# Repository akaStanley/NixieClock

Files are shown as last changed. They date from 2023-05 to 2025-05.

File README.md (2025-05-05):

# Nixie Tube Clock
From scratch design of a Nixie Tube Clock, with a twist. This clock sets its time using a GPS reciever, so it has the correct time anywhere around the world--and you don't have set it.

Read the "Notes on Nixie Tube Clock.rtf" for more details on the actual design. Here are some images of the design.
All the Code, PCB, and 3D model files are included here if you want to make your own. BOM cost will run you around 300$ (as of May 2025)

### The Finnished Clock
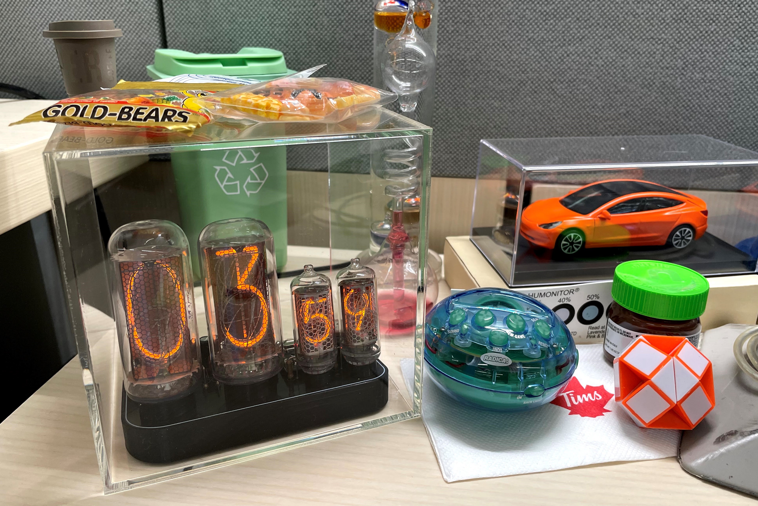
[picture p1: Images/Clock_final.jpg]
Clock Final


### The Clock Powered Off
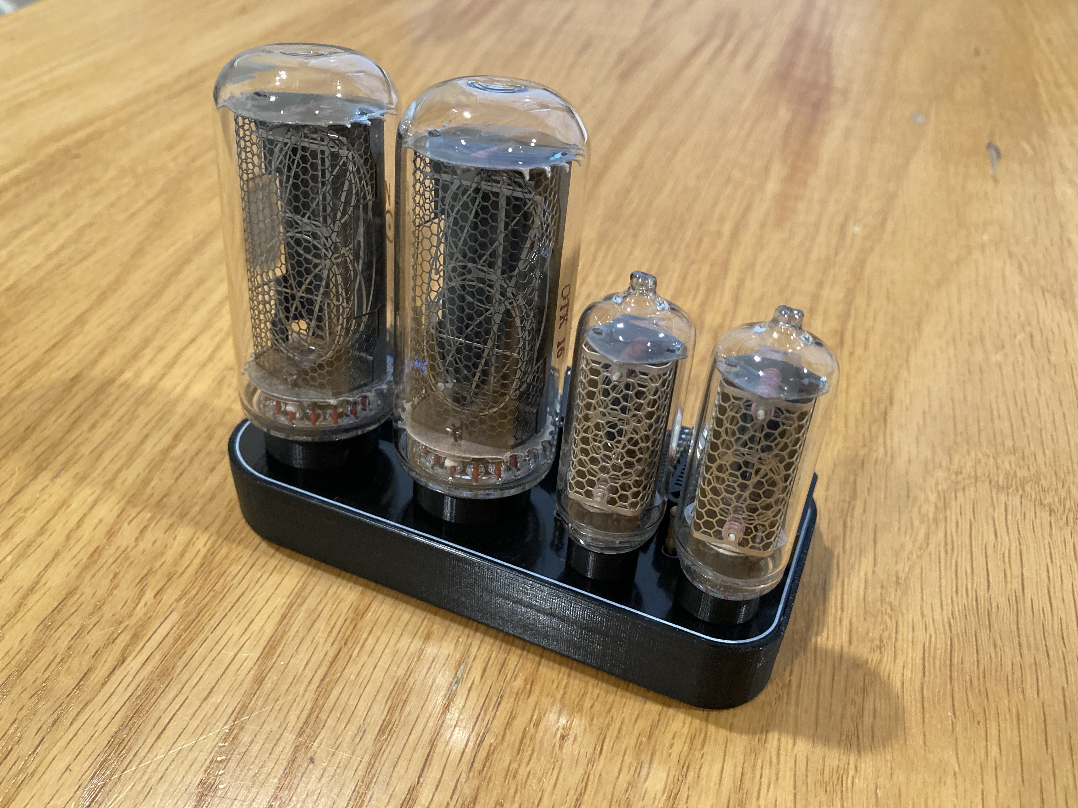
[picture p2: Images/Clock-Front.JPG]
Clock 3/4 view powered off


### PCB Top side
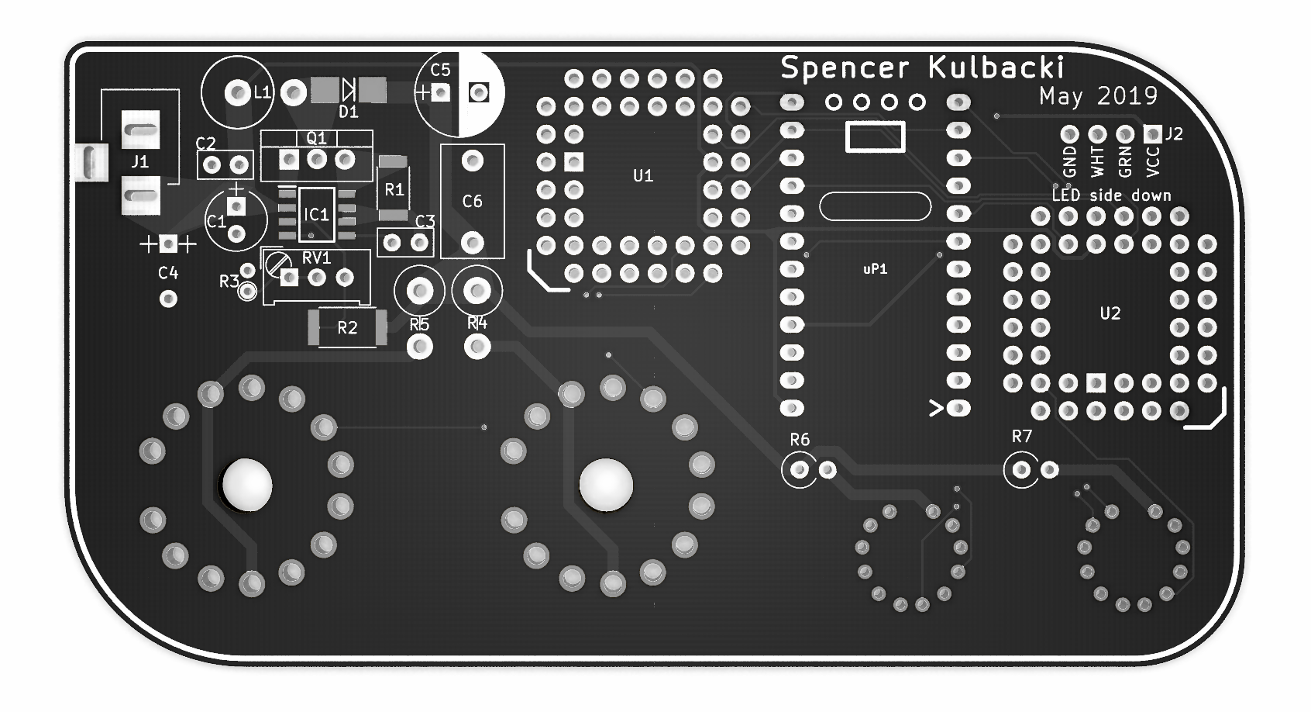
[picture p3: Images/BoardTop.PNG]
Board Top side


### PCB Bottom side (with fix)
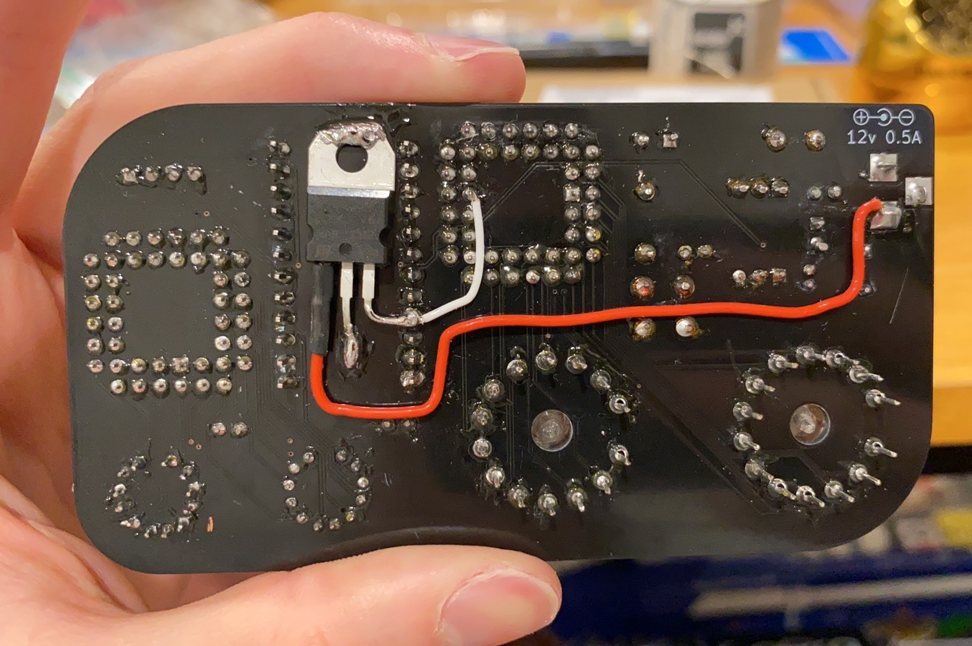
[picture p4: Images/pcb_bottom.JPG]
Board Bottom side with added 5v LDO


### Circuit Overview
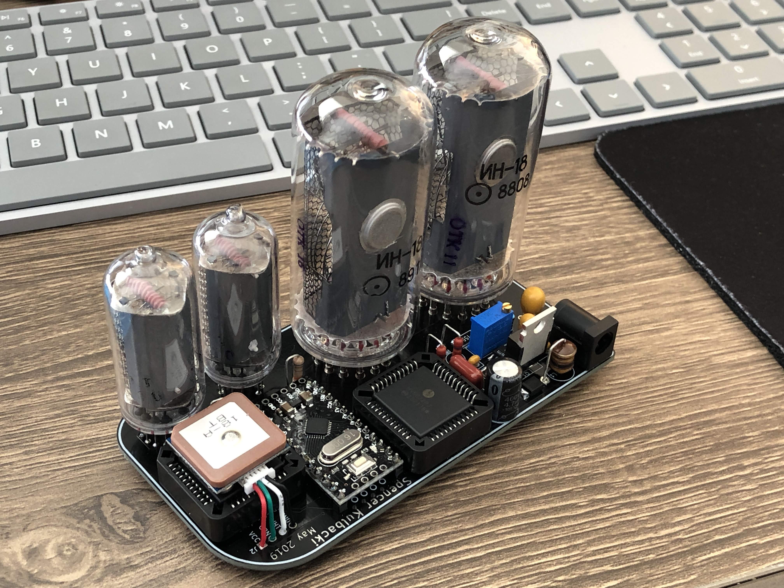
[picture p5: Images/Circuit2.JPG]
3/4 view of the GPS module, MCU and power supply


### Circuit Detail
From left to right:  
12vDC to 180v boost circuit Max1771, HV shift register 1 for Hours, arduino MCU, GPS antenna, HV shift register 2 for minutes (underneath GPS)  
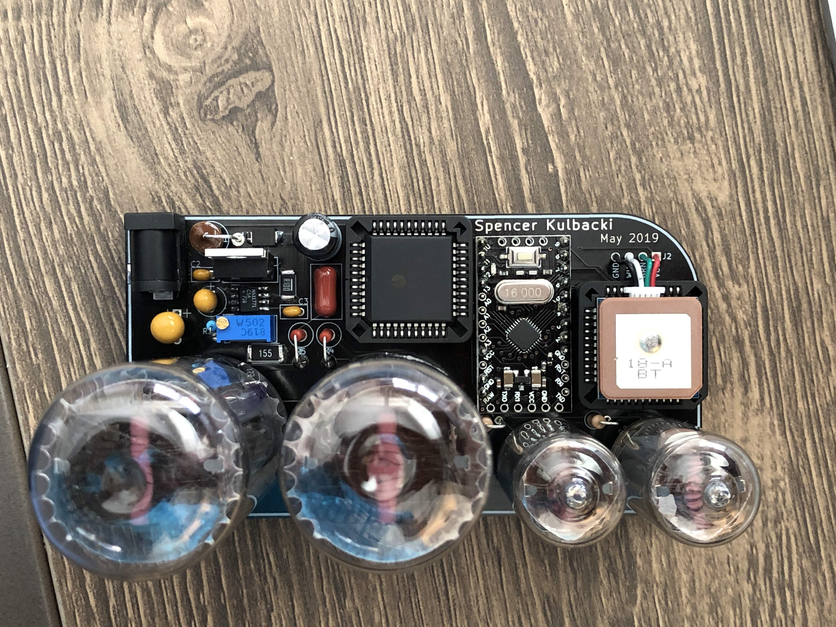
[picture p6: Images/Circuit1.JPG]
Top view of the GPS module, MCU and power supply


## 3D Printing
I bought an Ender 3 V2 and modeled a base and some trim parts for this clock.  

### "Naked" Tube legs
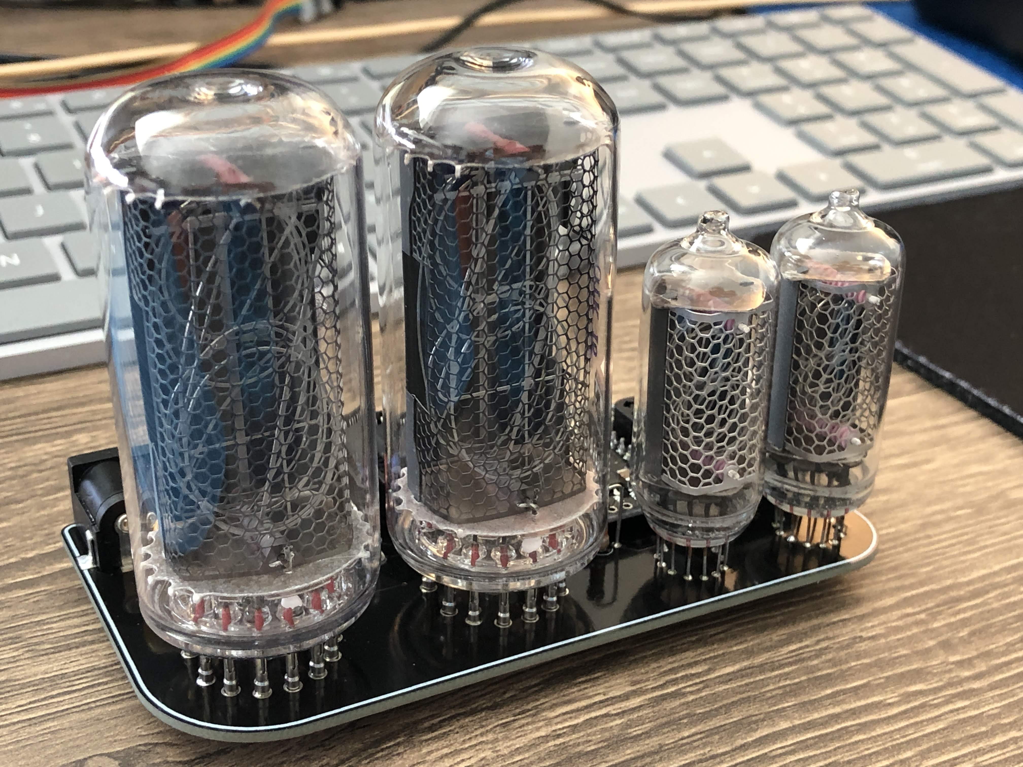
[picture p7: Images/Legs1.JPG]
Ugly


### Angled Base
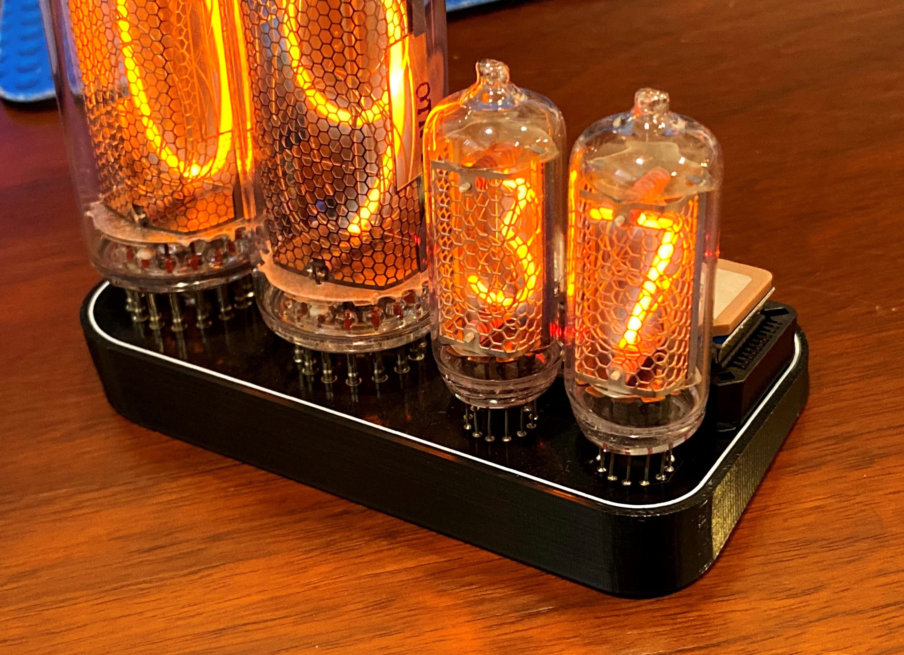
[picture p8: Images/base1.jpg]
Perfect viewing angle


### 3D printed ring to cover them
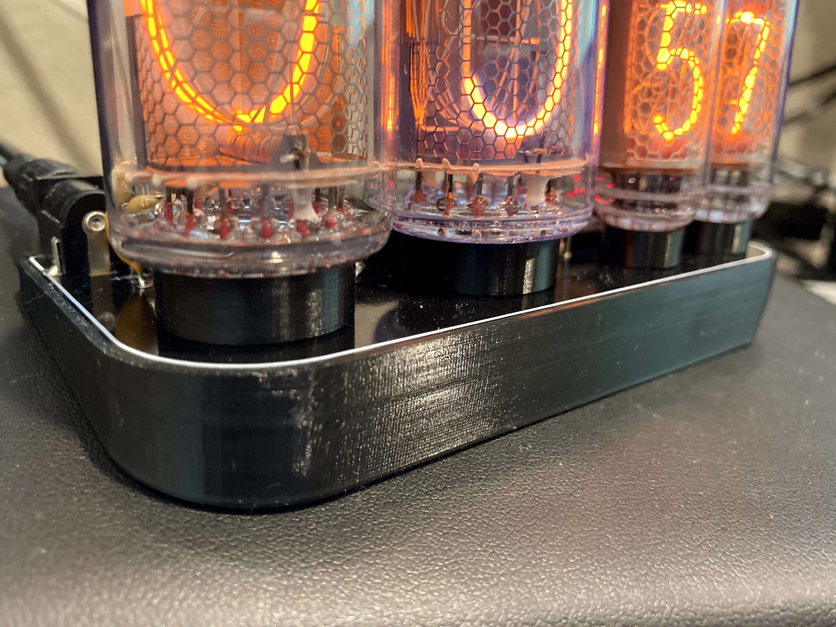
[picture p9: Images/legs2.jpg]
Elegant


## Tubes!
Like any old electronics one day they will _stop working_ ... and they aren't getting any cheaper to repair.  
In 2020, the larger IN-18 tubes were 50$ each, and the smaller IN-8-2 were a measly 18$. Shipped from a wearhouse in Belarus.  
Flash forward to 2025, and the large tubes are 85$ and the small IN-8-2 are now retailing for 25$ each.  
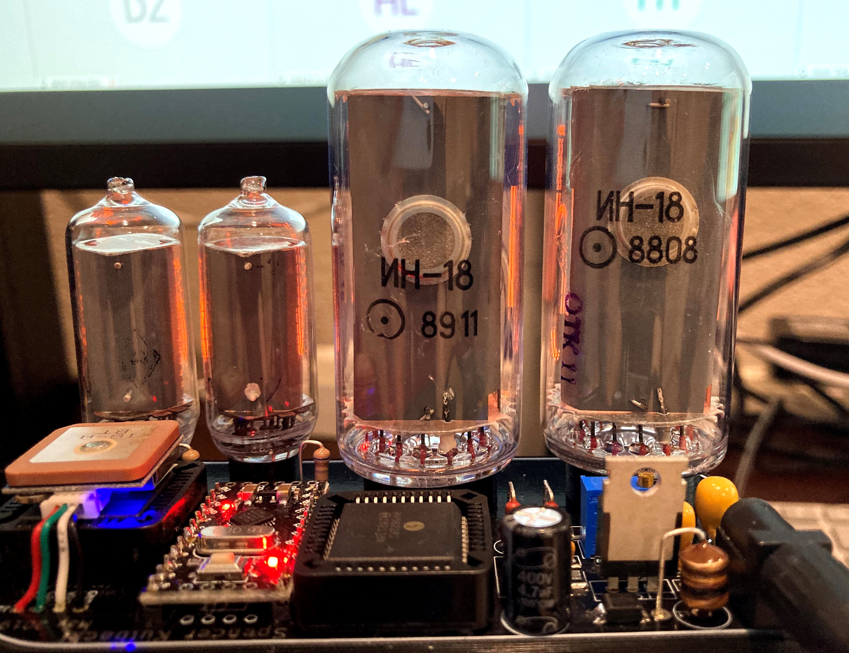
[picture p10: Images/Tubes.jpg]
IN-8-2 on the left, IN-18 on the right
  

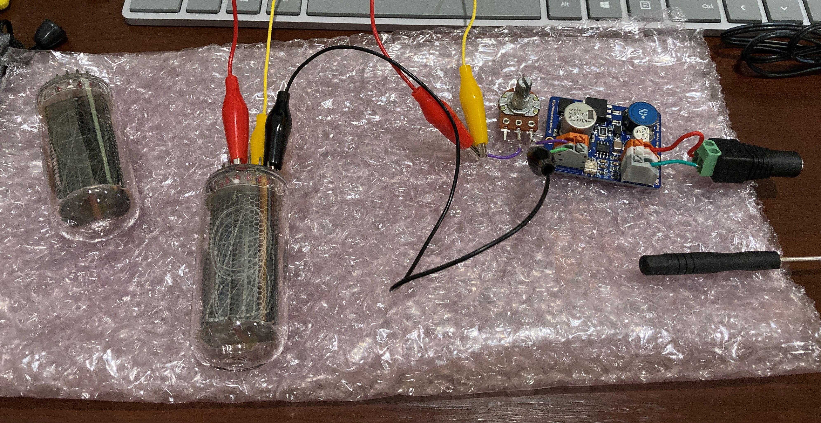
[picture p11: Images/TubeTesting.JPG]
Tube testing, hoping to bring one back from the dead


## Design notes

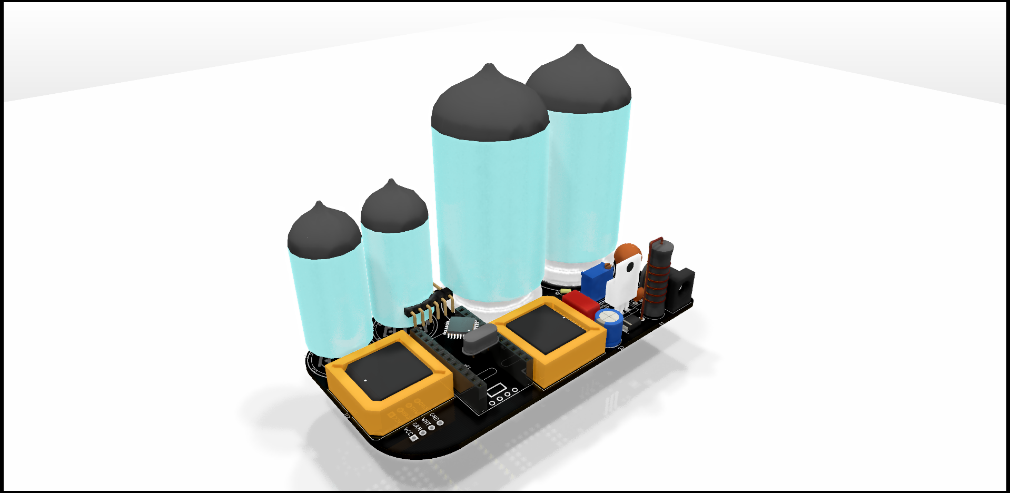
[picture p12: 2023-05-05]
Images/BackView1.png

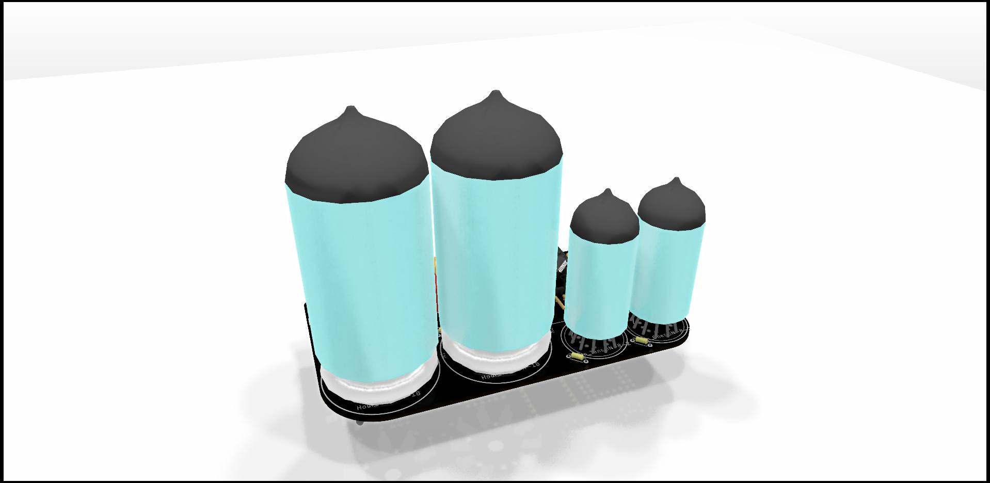
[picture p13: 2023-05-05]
Images/FrontView1.png

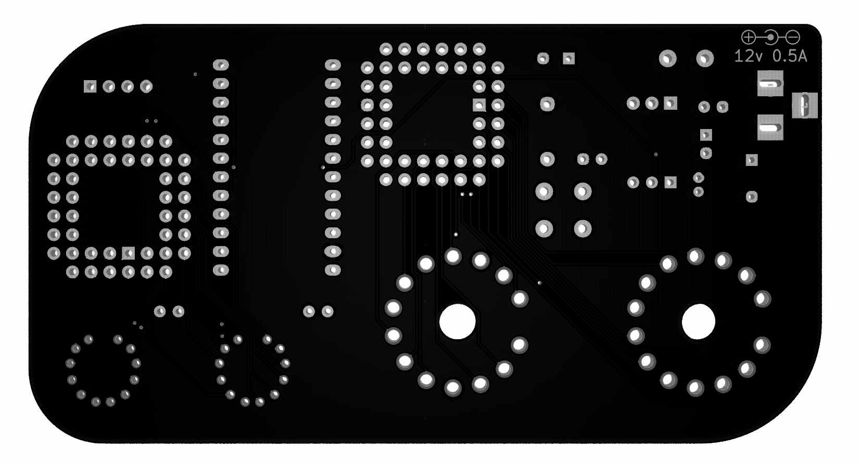
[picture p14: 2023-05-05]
Images/BoardBottom.PNG

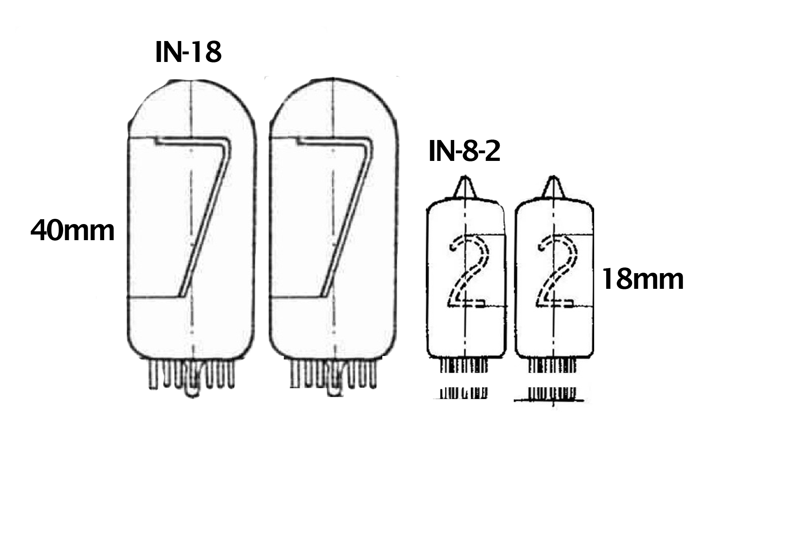
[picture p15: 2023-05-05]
Images/Clock Layout template.png

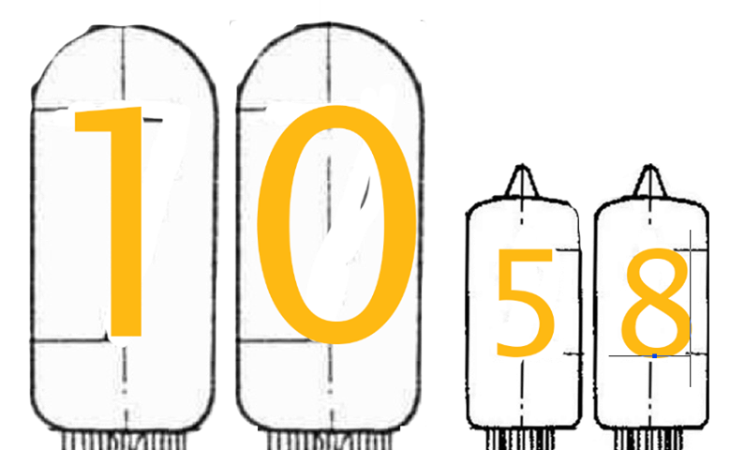
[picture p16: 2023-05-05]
Images/v1 big hr 1058.png

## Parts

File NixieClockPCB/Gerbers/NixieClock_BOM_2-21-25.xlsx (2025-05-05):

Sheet: NixieClockBOM
Nixie Clock PCB
Gen: 5/7/2019 8:15p |  |  | 82 | edited 2/21/2025
Component Count: |  |  | 20
Ref | QTY | Footprint | Value | Digikey Part # | Per Unit | Cost | Notes
D1 | 1 | D_SMB | ES2F | ES2F-E3/52TGICT-ND | 0.35 |  | Leftover.
N1-N4 | 28 | socket pins from DSUB |  | L77SDCH37SOL2-ND | 2.55 |  | Leftover. 14 pins each only for 2x big tubes
C1 | 1 | CP_Radial_Tantal_D5.5mm_P2.50mm | 10uF 25v | 478-6062-ND | 0.92 |  | Leftover.
R7,R6 | 2 | R_Axial_DIN0309_L9.0mm_D3.2mm_P2.54mm_Vertical | 68k | CF12JT68K0CT-ND | 0.1 |  | Leftover. 1/2 watt
C2,C3 | 2 | C_Disc_D5.0mm_W2.5mm_P2.50mm | 0.1uF | 399-4151-ND | 0.21 |  | Leftover.
C4 | 1 | CP_Radial_Tantal_D9.0mm_P5.00mm | 100uF 35v | 478-1847-ND | 1.93 |  | Leftover.
C6 | 1 | C_Rect_L10.3mm_W5.7mm_P7.50mm_MKS4 | 100n 250v | EF2104-ND | 0.3 |  | Leftover.
R4,R5 | 2 | R_Axial_DIN0414_L11.9mm_D4.5mm_P5.08mm_Vertical | 27k | PPC27KW-1CT-ND | 0.24 |  | Lefover. 1 watt
R2 | 1 | Resistors_SMD:R_2512 | 1M5 | PT1.5MXCT-ND | 0.46 |  | Lefover. 1 watt
PCB | 1 | 2 sided 1oz Copper Black PCB |  |  |  |  | Leftover.
R1 | 1 | R_2010 | 0R100 | YAG6029CT-ND | 0.61 |  | Leftover.
uP1 | 1 | pro_mini | ARDUPROMINI |  |  |  | Leftover.
J1 | 1 | BARREL_JACK | Barrel_Jack |  |  |  | Leftover.
R3 | 1 | R_Axial_DIN0204_L3.6mm_D1.6mm_P1.90mm_Vertical | 10k | Generic 10k 1/4w sense |  |  | Leftover.
U1,U2 | 2 | J-Lead for PLCC Socket | HV5622 | HV5622PJ-G-ND | 8.32 | 16.640
U1,U2 | 2 | PLCC-44_THT-Socket | A-CCS 044-Z-T | 123-A-CCS044-Z-T-ND | 1.7 | 3.400
Q1 | 1 | TO-220-3_Vertical | IRF644 PBF |  | 2.85 | 2.850 | IRF740AB OK substiute but hire RDS 0.5 vs .02 ohm
L1 | 1 | L_Axial_L26.0mm_D9.0mm_P5.08mm_Vertical_Fastron_77A | 100uH | 495-6781-1-ND | 0.51 | 0.510
C5 | 1 | CP_Radial_D8.0mm_P3.50mm | 4u7 250v |  | 0.86 | 0.860 | UVC2G4R7MPD Ideally less than 3ohm ESR
RV1 | 1 | Potentiometer_Trimmer_Bourns_PV36W | 5k | 118-PV36W502C01B00-ND | 1.53 | 1.530
 | 1 | 12v 0.5A DC Barrel Jack wall supply |  |  |  |  | Leftover.
J2 | 1 | GPS_BN180 | GPS | AliExpress | 9.6 | 9.600
IC1 | 1 | SOIC127P600X175-8N | MAX1771ESA+ | Aliexpress | 0.714 | 0.714 | Leftover (possibly)
N3,N4 | 2 | nixies-us-IN-8-2 | IN-8-2 | Ebay | 83.3 | 166.600
N1,N2 | 2 | nixies-us-IN-18-DSUB | IN-18 | Ebay | 24.9 | 49.800
 | 1 | Clear Acrylic 5-Sided Cube 5" x 5" x 5" - Open One Side |  | Ebay | 19.99 | 19.990
 |  |  |  | Current Total BOM Cost: |  | 272.4940

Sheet: Power calc
Item | Votla | amps | Watts worst case
Big tube | 170 | 0.008 | 1.36
Big tube | 170 | 0.008 | 1.36
Smal tube | 170 | 0.0045 | 0.765
Smal tube | 170 | 0.0045 | 0.765
Shift reg | 12 | 0.03 | 0.36
Shift reg | 12 | 0.03 | 0.36
Adruino | 5 | 0.025 | 0.125
GPS | 5 | 0.05 | 0.25
 |  |  | 5.345 | 0.5
 |  |  |  | amps of 12v
 | recommend 12v 500mA supply

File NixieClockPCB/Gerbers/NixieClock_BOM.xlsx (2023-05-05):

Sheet: NixieClockBOM
Nixie Clock PCB
Gen: 5/7/2019 8:15p |  |  | 82 | edited 5/7/2019
Component Count: |  |  | 82
Ref | QTY | Footprint | Value | Digikey Part # | Per Unit | Cost | Notes
U1,U2 | 2 | J-Lead for PLCC Socket | HV5622 | HV5622PJ-G-ND | 5.07 | 10.1400
U1,U2 | 2 | PLCC-44_THT-Socket |  | AE10057-ND | 1.02 | 2.0400
J2 | 1 | GPS_BN180 | GPS | x | 15.98 |  | Purchased
D1 | 1 | D_SMB | ES2F | ES2F-E3/52TGICT-ND | 0.51 | 0.5100
L1 | 1 | L_Axial_L26.0mm_D9.0mm_P5.08mm_Vertical_Fastron_77A | 100uH | 495-6781-1-ND | 0.96 | 0.9600
N3,N4 | 2 | nixies-us-IN-8-2 | IN-8-2 | x | 50 |  | Purchased
N1,N2 | 2 | nixies-us-IN-18-DSUB | IN-18 | x | 20 |  | Purchased
N1-N4 | 52 | socket pins from DSUB |  | L77SDCH37SOL2-ND | 2.55 | 5.1000
uP1 | 1 | pro_mini | ARDUPROMINI | x |  |  | Purchased
C1 | 1 | CP_Radial_Tantal_D5.5mm_P2.50mm | 10uF 25v | 478-6062-ND | 0.92 | 0.9200
R7,R6 | 2 | R_Axial_DIN0309_L9.0mm_D3.2mm_P2.54mm_Vertical | 68k | CF12JT68K0CT-ND | 0.1 | 0.2000 | 1/2 watt
C2,C3 | 2 | C_Disc_D5.0mm_W2.5mm_P2.50mm | 0.1uF | 399-4151-ND | 0.21 | 0.4200
C4 | 1 | CP_Radial_Tantal_D9.0mm_P5.00mm | 100uF 35v | 478-1847-ND | 1.93 | 1.9300 | alternate: 399-15741-ND (Maybe?)
C5 | 1 | CP_Radial_D8.0mm_P3.50mm | 4u7 250v | x |  |  | Purchased
C6 | 1 | C_Rect_L10.3mm_W5.7mm_P7.50mm_MKS4 | 100n 250v | EF2104-ND | 0.3 | 0.3000
J1 | 1 | BARREL_JACK | Barrel_Jack | x |  |  | Purchased
Q1 | 1 | TO-220-3_Vertical | IRF644 PBF | x |  | 0.0000 | IRF740AB purchased OK substiute
R1 | 1 | R_2010 | 0R100 | YAG6029CT-ND | 0.61 | 0.6100
R3 | 1 | R_Axial_DIN0204_L3.6mm_D1.6mm_P1.90mm_Vertical | 10k | x |  |  | 1/4w Purchased
RV1 | 1 | Potentiometer_Trimmer_Bourns_PV36W | 5k | 490-2888-ND | 1.5 | 1.5000
IC1 | 1 | SOIC127P600X175-8N | MAX1771ESA+ | x |  |  | Purchased
R4,R5 | 2 | R_Axial_DIN0414_L11.9mm_D4.5mm_P5.08mm_Vertical | 27k | PPC27KW-1CT-ND | 0.24 | 0.4800 | 1 watt
R2 | 1 | Resistors_SMD:R_2512 | 1M5 | PT1.5MXCT-ND | 0.46 | 0.4600 | 1 watt
PCB | 1 | 2 sided 1oz Copper Black PCB |  |  |  | 0.0000
 |  |  |  |  |  | 0.0000
 |  |  |  |  |  | 0.0000
 |  |  |  |  |  | 0.0000
 |  |  |  |  |  | 0.0000
 |  |  |  |  |  | 0.0000
 |  |  |  |  | 25.5700

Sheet: Power calc
Item | Votla | amps | Watts worst case
Big tube | 170 | 0.008 | 1.36
Big tube | 170 | 0.008 | 1.36
Smal tube | 170 | 0.0045 | 0.765
Smal tube | 170 | 0.0045 | 0.765
Shift reg | 12 | 0.03 | 0.36
Shift reg | 12 | 0.03 | 0.36
Adruino | 5 | 0.025 | 0.125
GPS | 5 | 0.05 | 0.25
 |  |  | 5.345 | 0.5
 |  |  |  | amps of 12v
 | recommend 12v 500mA supply

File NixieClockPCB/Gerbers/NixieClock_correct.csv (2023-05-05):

Id | Designator | Package | Quantity | Designation | Supplier and ref
1 | U1,U2 | PLCC-44_THT-Socket | 2 | HV5622
2 | N2 | nixies-us-IN-18-DSUB | 1 | Hour_Ones_IN-18
3 | J2 | GPS_BN180 | 1 | GPS
4 | D1 | D_SMB | 1 | ES2F
5 | L1 | L_Axial_L26.0mm_D9.0mm_P5.08mm_Vertical_Fastron_77A | 1 | 100uH
6 | N4 | nixies-us-IN-8-2 | 1 | Min_Ones_IN-8-2
7 | N3 | nixies-us-IN-8-2 | 1 | Min_Tens_IN-8-2
8 | N1 | nixies-us-IN-18-DSUB | 1 | Hour_Tens_IN-18
9 | uP1 | pro_mini | 1 | ARDUPROMINI
10 | C1 | CP_Radial_Tantal_D5.5mm_P2.50mm | 1 | 10uF 25v
11 | R7,R6 | R_Axial_DIN0309_L9.0mm_D3.2mm_P2.54mm_Vertical | 2 | 68k
12 | C2,C3 | C_Disc_D5.0mm_W2.5mm_P2.50mm | 2 | 100n
13 | C4 | CP_Radial_Tantal_D9.0mm_P5.00mm | 1 | 100uF 35v
14 | C5 | CP_Radial_D8.0mm_P3.50mm | 1 | 4u7 250v
15 | C6 | C_Rect_L10.3mm_W5.7mm_P7.50mm_MKS4 | 1 | 100n 250v
16 | J1 | BARREL_JACK | 1 | Barrel_Jack
17 | Q1 | TO-220-3_Vertical | 1 | IRF644 PBF
18 | R1 | R_2010 | 1 | 0R100
19 | R3 | R_Axial_DIN0204_L3.6mm_D1.6mm_P1.90mm_Vertical | 1 | 10k
20 | RV1 | Potentiometer_Trimmer_Bourns_PV36W | 1 | 5k
21 | IC1 | SOIC127P600X175-8N | 1 | MAX1771ESA+
22 | R4,R5 | R_Axial_DIN0414_L11.9mm_D4.5mm_P5.08mm_Vertical | 2 | 27k
23 | R2 | R_Axial_DIN0414_L11.9mm_D4.5mm_P5.08mm_Vertical | 1 | 1M5

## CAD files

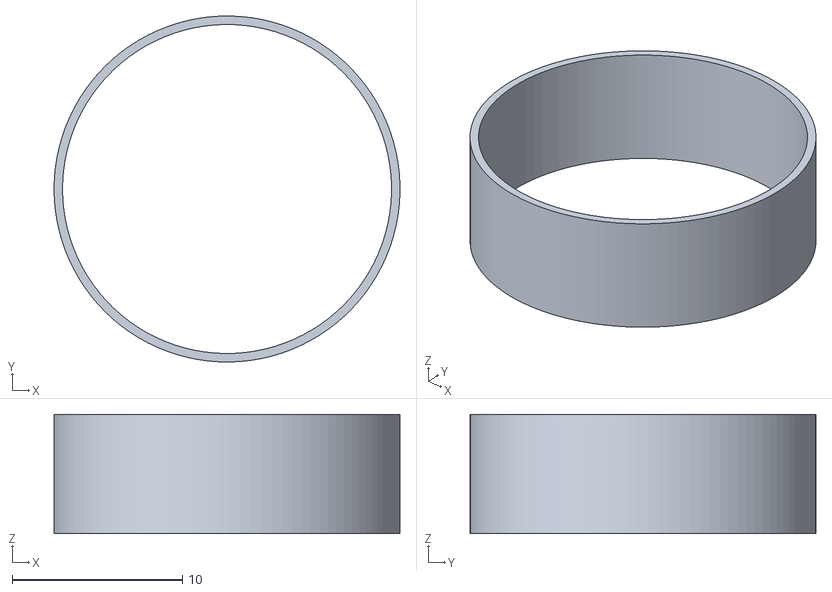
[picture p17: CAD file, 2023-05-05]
3D_Printed_Parts/BigCollar1.stl
20.3 x 20.3 x 7.00

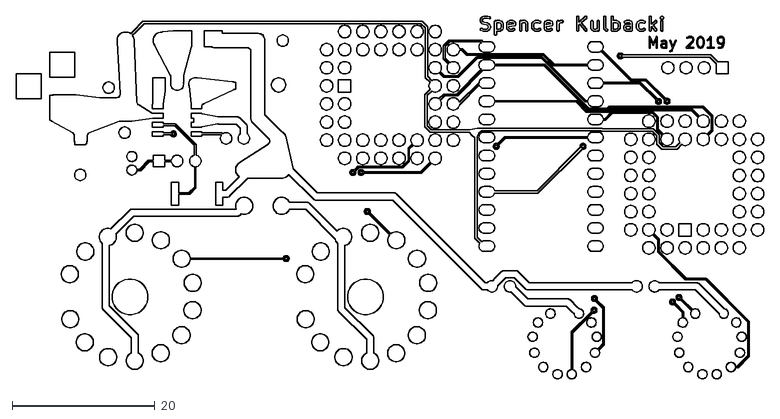
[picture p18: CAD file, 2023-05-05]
NixieClockPCB/NixieClock-F_Cu.dxf
104.9 x 50.9

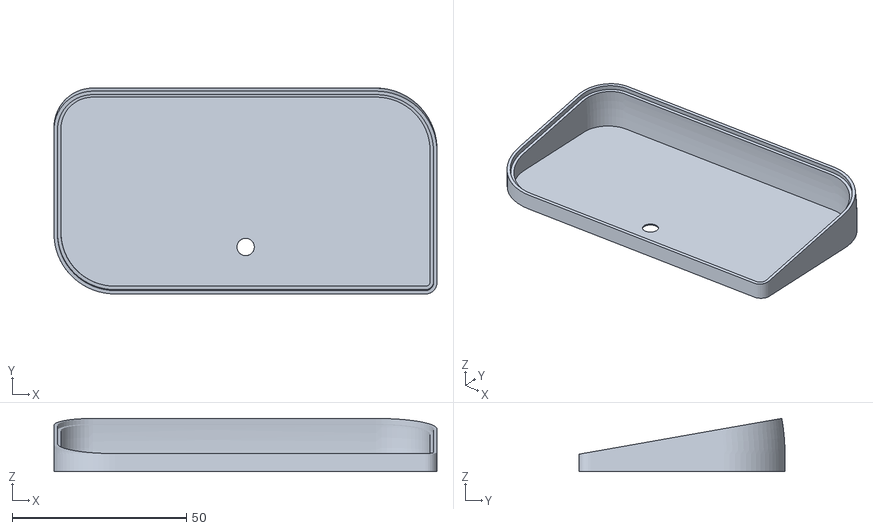
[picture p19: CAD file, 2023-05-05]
3D_Printed_Parts/3D_ClockBase_hole.stl
109.9 x 59.1 x 15.3

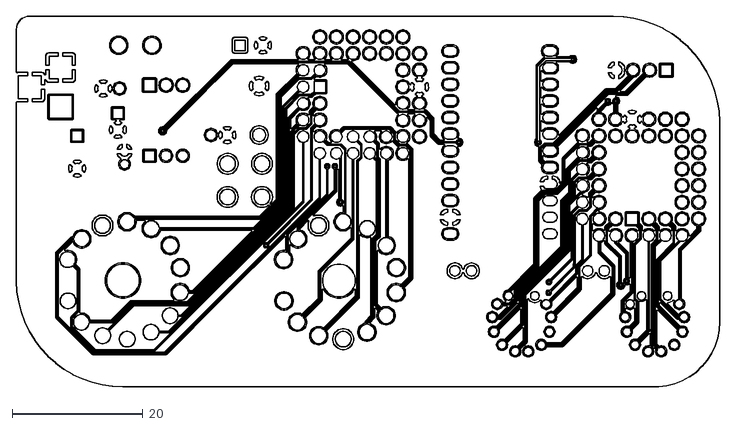
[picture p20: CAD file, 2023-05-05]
NixieClockPCB/NixieClock-B_Cu.dxf
107.5 x 56.7

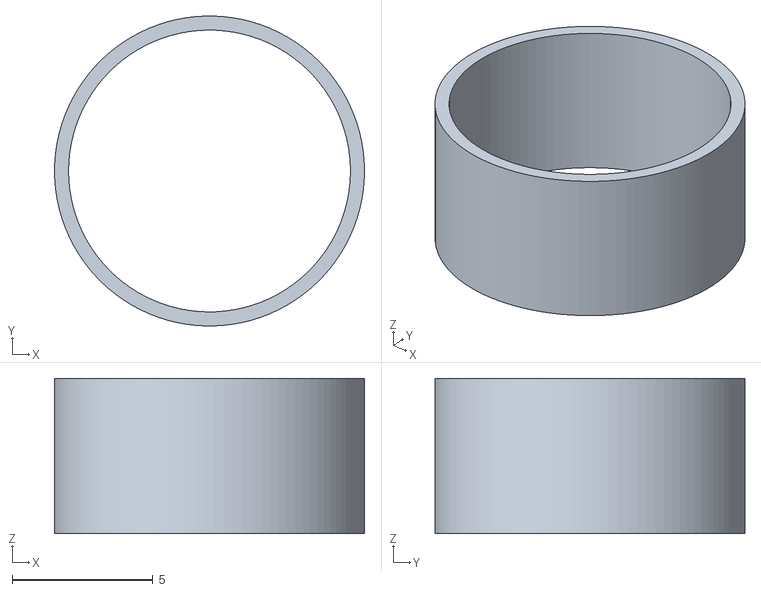
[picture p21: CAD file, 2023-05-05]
3D_Printed_Parts/SmallCollar1.stl
11.0 x 11.0 x 5.50

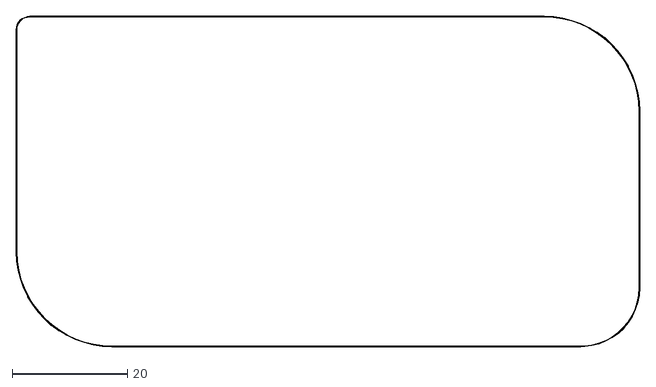
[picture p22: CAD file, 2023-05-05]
NixieClockPCB/NixieClock-Edge_Cuts.dxf
108.0 x 57.2

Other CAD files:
3D_Printed_Parts/3D_ClockBase.ipt
3D_Printed_Parts/BigCollar1.ipt

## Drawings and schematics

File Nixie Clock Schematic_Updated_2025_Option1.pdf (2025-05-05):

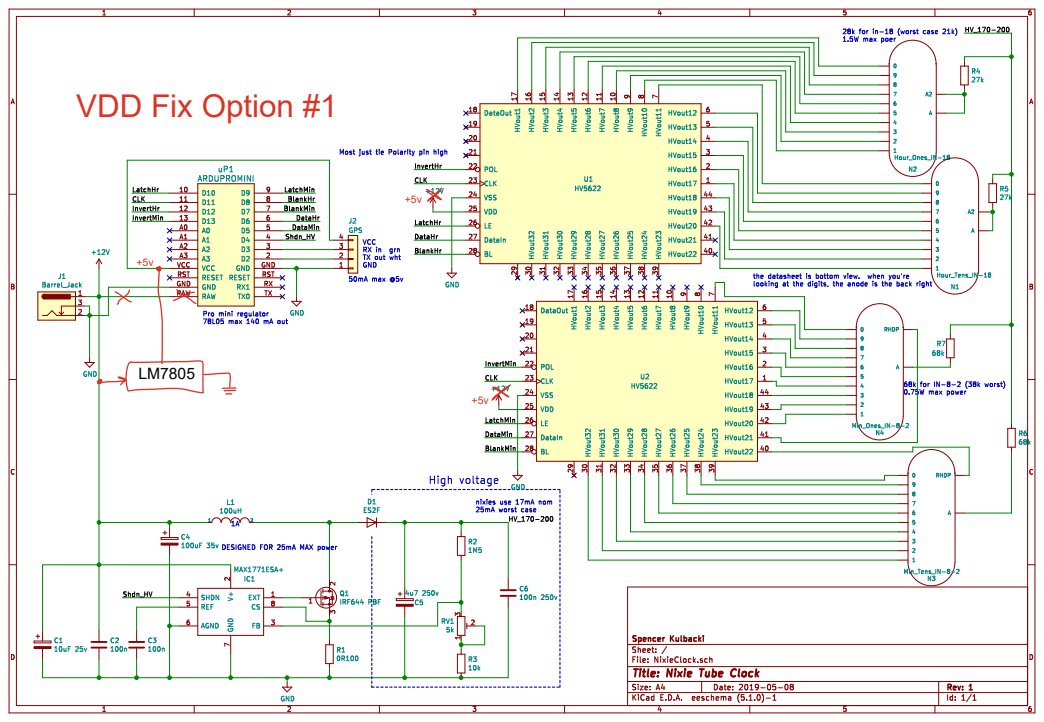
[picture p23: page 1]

VDD Fix Option #1

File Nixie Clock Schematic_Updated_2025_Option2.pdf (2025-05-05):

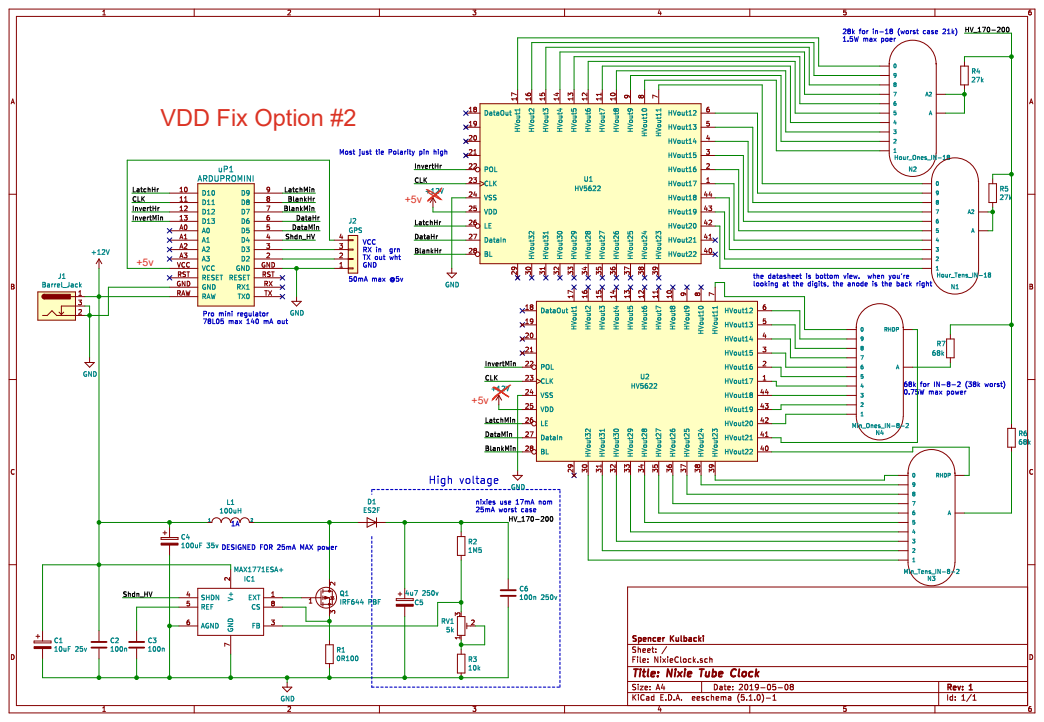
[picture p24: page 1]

VDD Fix Option #2

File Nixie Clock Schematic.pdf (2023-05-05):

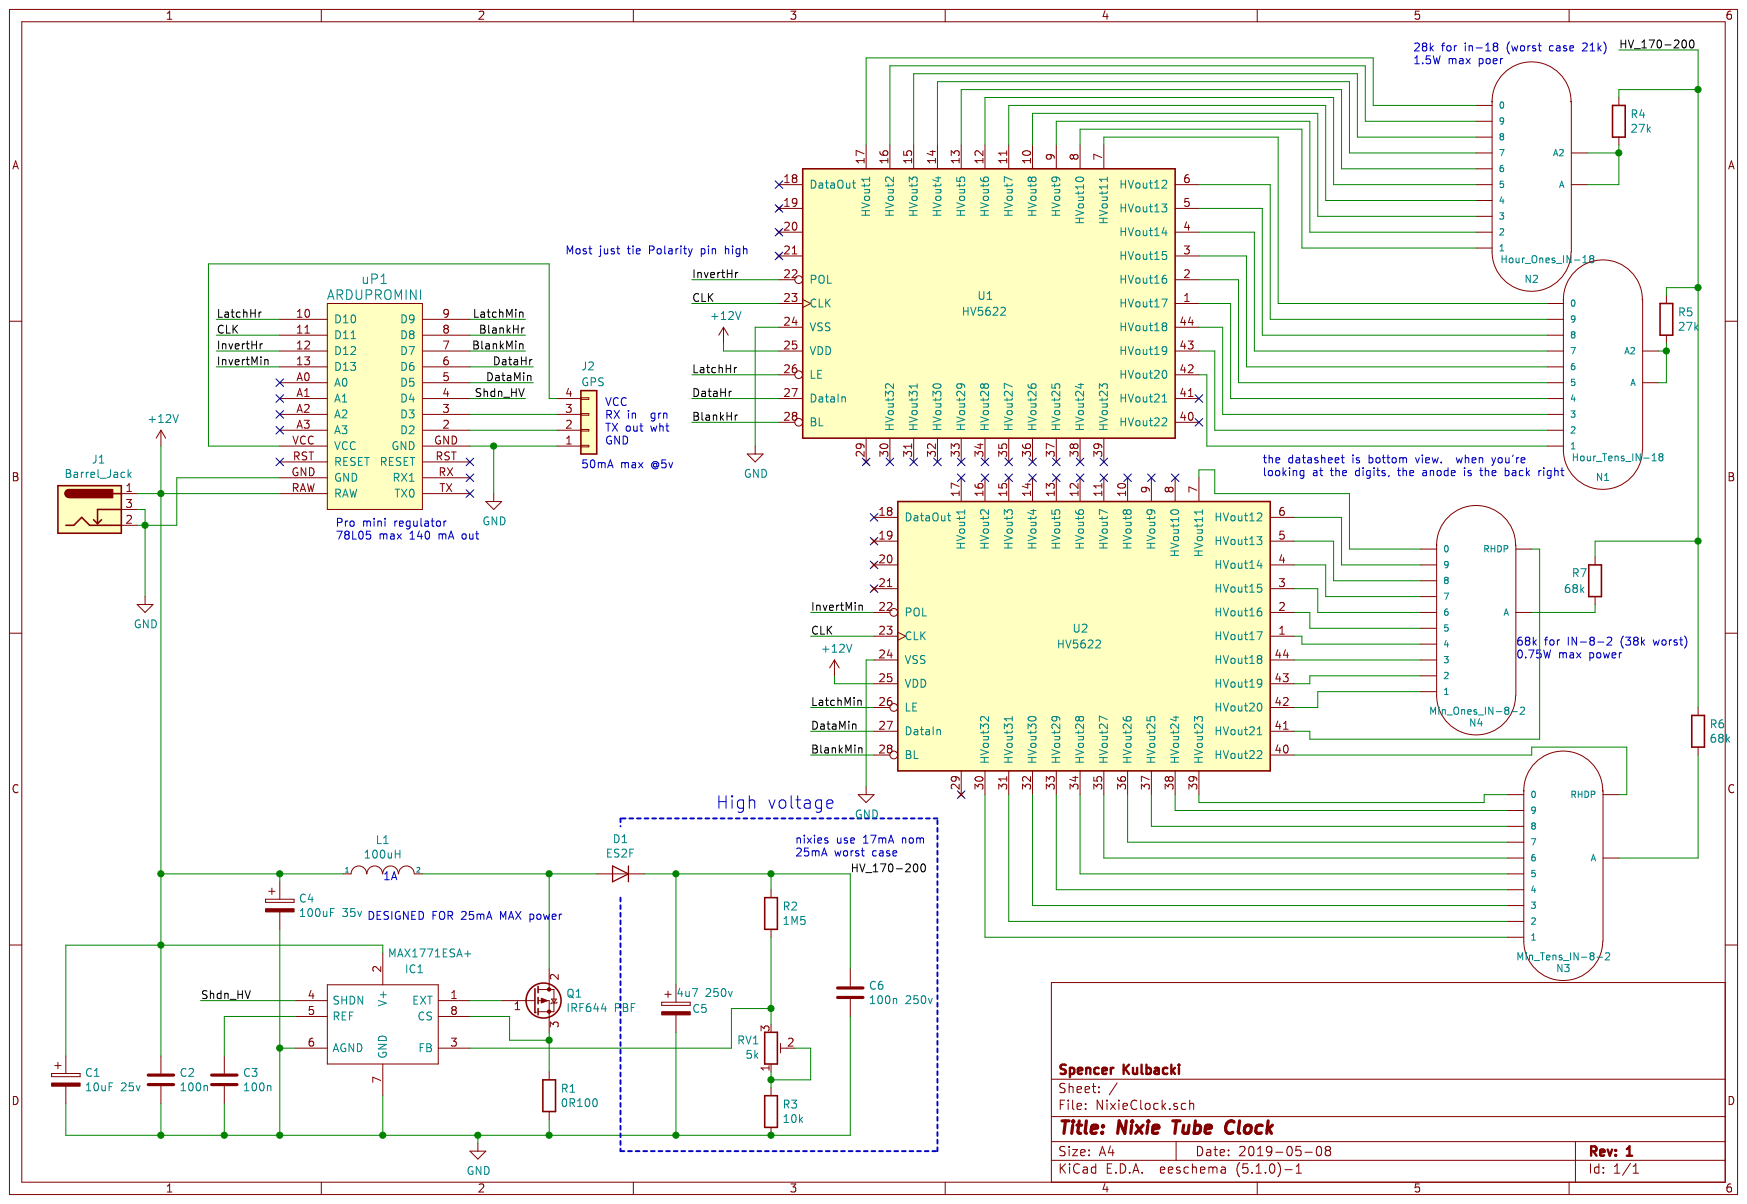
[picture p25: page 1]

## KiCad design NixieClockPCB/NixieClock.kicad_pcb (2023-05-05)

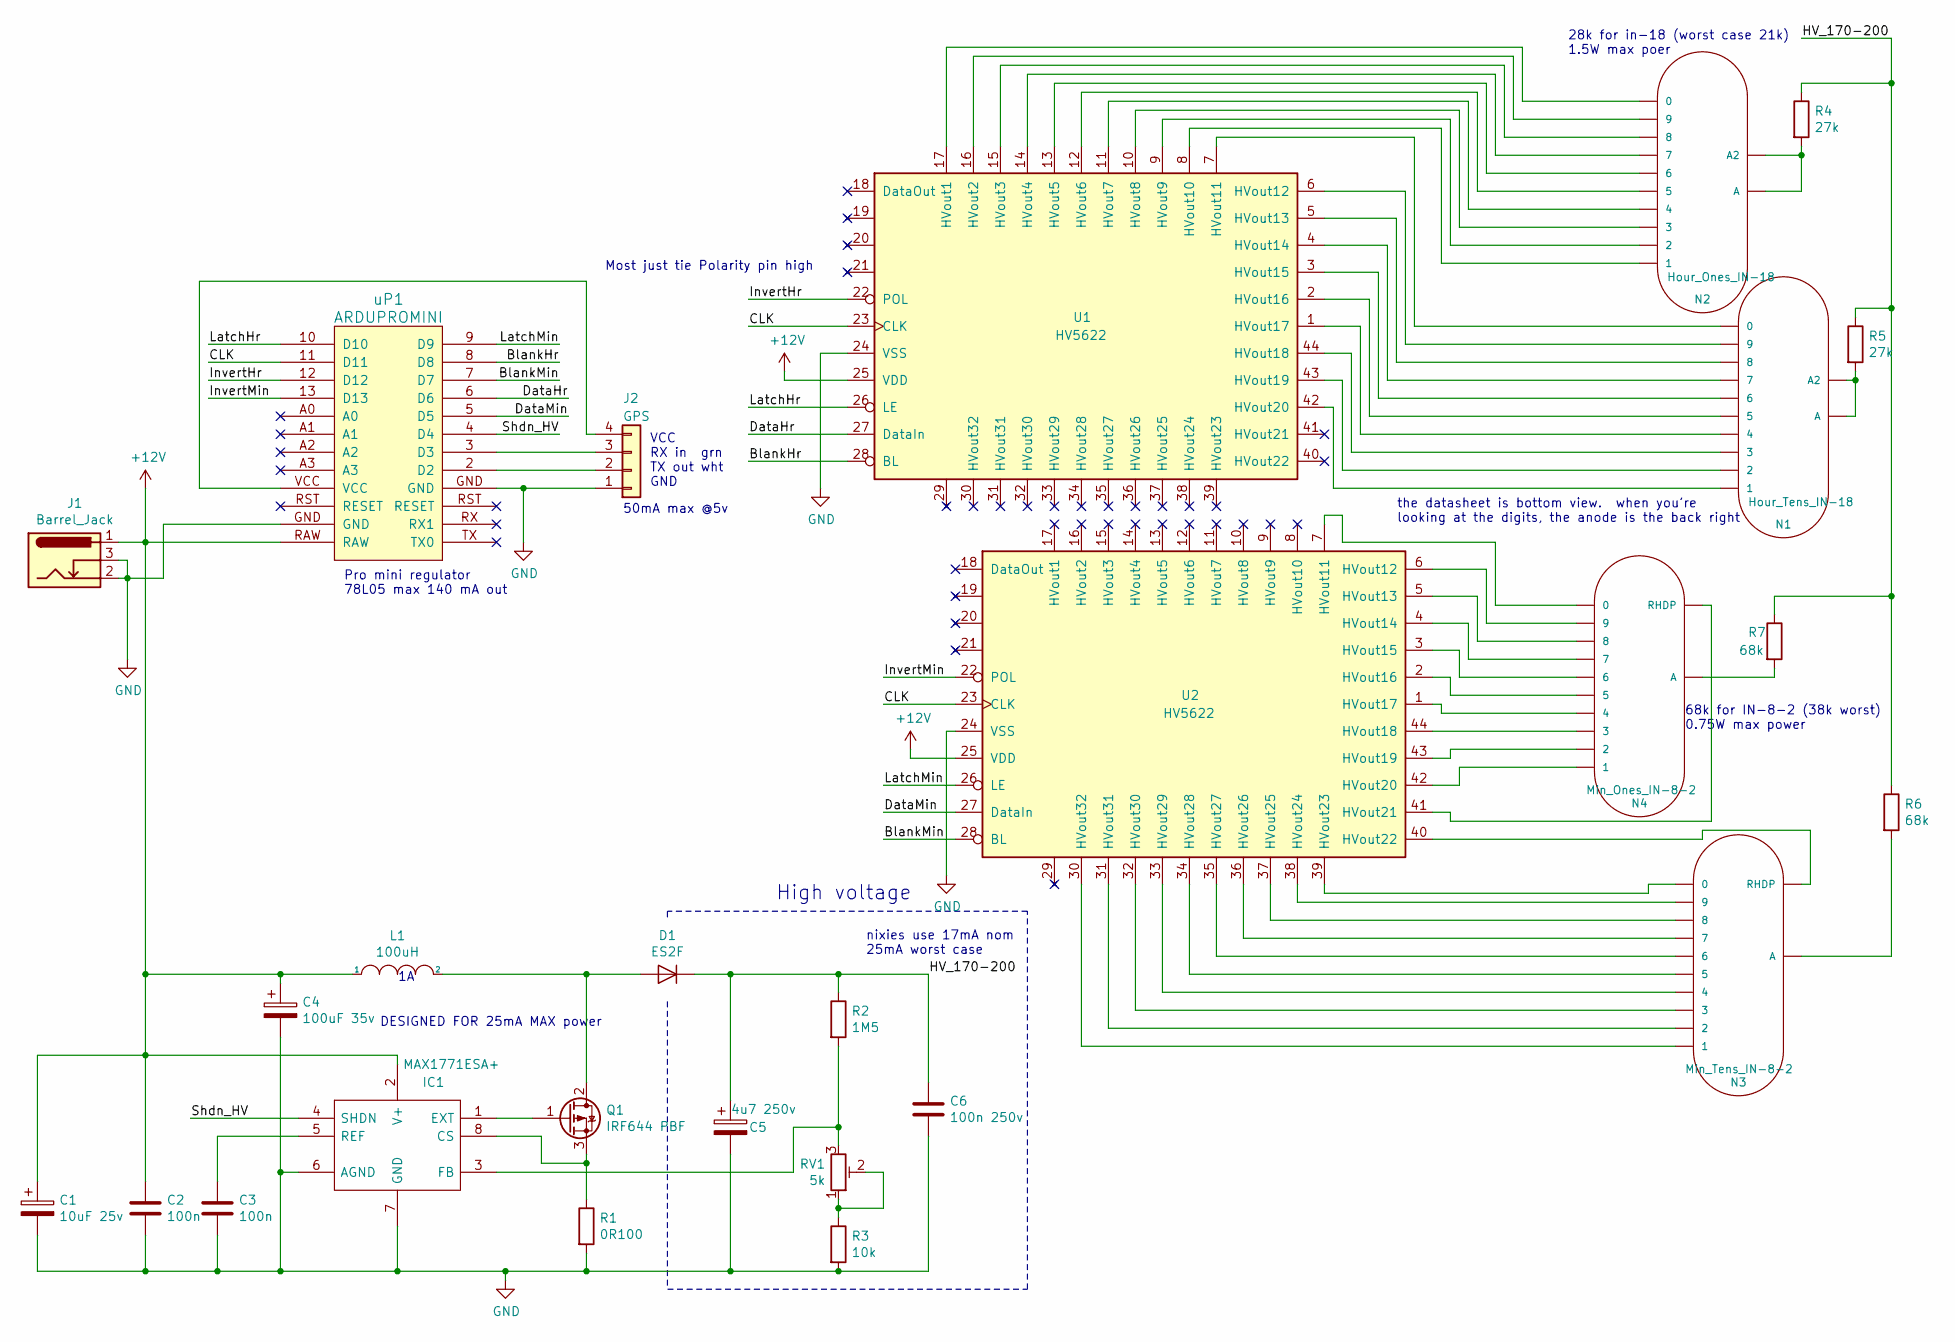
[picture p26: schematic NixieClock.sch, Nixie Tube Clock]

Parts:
C1: 10uF 25v; CP_Radial_Tantal_D5.5mm_P2.50mm
C2, C3: 100n; C_Disc_D5.0mm_W2.5mm_P2.50mm
C4: 100uF 35v; CP_Radial_Tantal_D9.0mm_P5.00mm
C5: 4u7 250v; CP_Radial_D8.0mm_P3.50mm
C6: 100n 250v; C_Rect_L10.3mm_W5.7mm_P7.50mm_MKS4
D1: ES2F; D_SMB
IC1: MAX1771ESA+; SOIC127P600X175-8N; Manufacturer_Part_Number MAX1771ESA+
J1: Barrel_Jack; BARREL_JACK
J2: GPS; GPS_BN180
L1: 100uH; L_Axial_L26.0mm_D9.0mm_P5.08mm_Vertical_Fastron_77A
N1: Hour_Tens_IN-18; nixies-us-IN-18-DSUB
N2: Hour_Ones_IN-18; nixies-us-IN-18-DSUB
N3: Min_Tens_IN-8-2; nixies-us-IN-8-2
N4: Min_Ones_IN-8-2; nixies-us-IN-8-2
Q1: IRF644 PBF; TO-220-3_Vertical
R1: 0R100; R_2010
R2: 1M5; R_Axial_DIN0414_L11.9mm_D4.5mm_P5.08mm_Vertical
R3: 10k; R_Axial_DIN0204_L3.6mm_D1.6mm_P1.90mm_Vertical
R4, R5: 27k; R_Axial_DIN0414_L11.9mm_D4.5mm_P5.08mm_Vertical
R6, R7: 68k; R_Axial_DIN0309_L9.0mm_D3.2mm_P2.54mm_Vertical
RV1: 5k; Potentiometer_Trimmer_Bourns_PV36W
U1, U2: HV5622; PLCC-44_THT-Socket
uP1: ARDUPROMINI; pro_mini

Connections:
+12V: C1.1, C2.1, C4.1, IC1.2 (V+), J1.1, L1.1, U1.25 (VDD), U2.25 (VDD), uP1.RAW
/BlankHr: U1.28 (BL), uP1.8 (D8)
/BlankMin: U2.28 (BL), uP1.7 (D7)
/CLK: U1.23 (CLK), U2.23 (CLK), uP1.11 (D11)
/DataHr: U1.27 (DataIn), uP1.6 (D6)
/DataMin: U2.27 (DataIn), uP1.5 (D5)
/HV_170-200: C5.1, C6.1, D1.1 (K), R2.1, R4.1, R5.1, R6.1, R7.1
/InvertHr: U1.22 (POL), uP1.12 (D12)
/InvertMin: U2.22 (POL), uP1.13 (D13)
/LatchHr: U1.26 (LE), uP1.10 (D10)
/LatchMin: U2.26 (LE), uP1.9 (D9)
/Shdn_HV: IC1.4 (SHDN), uP1.4 (D4)
GND: C1.2, C2.2, C3.2, C4.2, C5.2, C6.2, IC1.6 (AGND), IC1.7 (GND), J1.2, J1.3, J2.1, R1.2, R3.2, U1.24 (VSS), U2.24 (VSS), uP1.GND
unnamed: C3.1, IC1.5 (REF)
unnamed: D1.2 (A), L1.2, Q1.2 (D)
unnamed: IC1.1 (EXT), Q1.1 (G)
unnamed: IC1.3 (FB), R2.2, RV1.3
unnamed: IC1.8 (CS), Q1.3 (S), R1.1
unnamed: J2.2, uP1.2 (D2)
unnamed: J2.3, uP1.3 (D3)
unnamed: J2.4, uP1.VCC
unnamed: N1.0, U1.7 (HVout11)
unnamed: N1.1, U1.42 (HVout20)
unnamed: N1.2, U1.43 (HVout19)
unnamed: N1.3, U1.44 (HVout18)
unnamed: N1.4, U1.1 (HVout17)
unnamed: N1.5, U1.2 (HVout16)
unnamed: N1.6, U1.3 (HVout15)
unnamed: N1.7, U1.4 (HVout14)
unnamed: N1.8, U1.5 (HVout13)
unnamed: N1.9, U1.6 (HVout12)
unnamed: N1.A, N1.A2, R5.2
unnamed: N2.0, U1.17 (HVout1)
unnamed: N2.1, U1.8 (HVout10)
unnamed: N2.2, U1.9 (HVout9)
unnamed: N2.3, U1.10 (HVout8)
unnamed: N2.4, U1.11 (HVout7)
unnamed: N2.5, U1.12 (HVout6)
unnamed: N2.6, U1.13 (HVout5)
unnamed: N2.7, U1.14 (HVout4)
unnamed: N2.8, U1.15 (HVout3)
unnamed: N2.9, U1.16 (HVout2)
unnamed: N2.A, N2.A2, R4.2
unnamed: N3.0, U2.39 (HVout23)
unnamed: N3.1, U2.30 (HVout32)
unnamed: N3.2, U2.31 (HVout31)
unnamed: N3.3, U2.32 (HVout30)
unnamed: N3.4, U2.33 (HVout29)
unnamed: N3.5, U2.34 (HVout28)
unnamed: N3.6, U2.35 (HVout27)
unnamed: N3.7, U2.36 (HVout26)
unnamed: N3.8, U2.37 (HVout25)
unnamed: N3.9, U2.38 (HVout24)
unnamed: N3.. (RHDP), U2.40 (HVout22)
unnamed: N3.A, R6.2
unnamed: N4.0, U2.7 (HVout11)
unnamed: N4.1, U2.42 (HVout20)
unnamed: N4.2, U2.43 (HVout19)
unnamed: N4.3, U2.44 (HVout18)
unnamed: N4.4, U2.1 (HVout17)
unnamed: N4.5, U2.2 (HVout16)
unnamed: N4.6, U2.3 (HVout15)
unnamed: N4.7, U2.4 (HVout14)
unnamed: N4.8, U2.5 (HVout13)
unnamed: N4.9, U2.6 (HVout12)
unnamed: N4.. (RHDP), U2.41 (HVout21)
unnamed: N4.A, R7.2
unnamed: R3.1, RV1.1, RV1.2

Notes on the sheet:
High voltage
VCC RX in grn TX out wht GND
50mA max @5v
DESIGNED FOR 25mA MAX power
nixies use 17mA nom 25mA worst case
the datasheet is bottom view. when you're looking at the digits, the anode is the back right
28k for in-18 (worst case 21k) 1.5W max poer
Pro mini regulator 78L05 max 140 mA out
68k for IN-8-2 (38k worst) 0.75W max power
Most just tie Polarity pin high

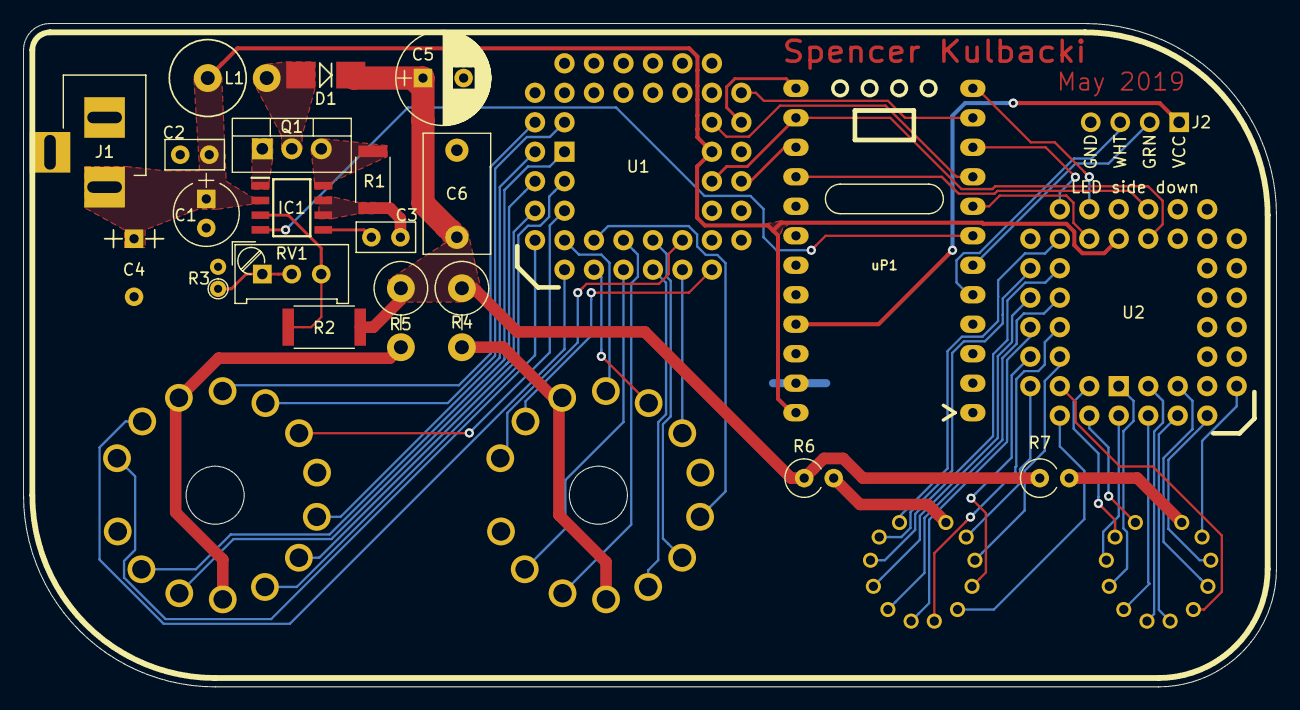
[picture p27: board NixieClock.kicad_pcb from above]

Board: 2 copper layers, 108.0 x 57.2 mm, 27 parts (0 on the bottom side), 68 nets.

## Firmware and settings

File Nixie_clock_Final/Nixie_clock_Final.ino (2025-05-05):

// May 5, 2025
// Spencer Kulbacki
// Nixie tube clock with GPS

//bn-180 pinout
//red   VCC (3.0-5.0v)
//green RX (input to chip)
//white TX (output from chip)
//black GND

//Exta Libraries Used:
//https://github.com/mikalhart/TinyGPSPlus
//https://github.com/JChristensen/Timezone
// Versions at compilation & last edit
// Arduino IDE ver 1.8.16
// TimeZone ver 1.2.4
// TinyGPSPlus ver 1.0.3

// Include Libraries
#include "SoftwareSerial.h"
#include "TinyGPSPlus.h"
#include "Timezone.h"
#include "TimeLib.h"  // Arduino library to work with time/date functions

static const int RXPin = 2, TXPin = 3;
//white to pin 3
//green to pin 2
// The serial connection to the GPS device
TinyGPSPlus gps;
SoftwareSerial ss(RXPin, TXPin);

bool TubeCleaning = true;

int TzoneOffset = -8; //used for time offset
time_t prevDisplay = 0; //when the time was last set
int stdOffsetMinutes = 0; //Standard Time offset
int dstOffsetMinutes = 0; //Daylight Time offset

const int clkPin = 11;   // OC2A output pin is 11 do not change
const int dataMin = 5;
const int dataHr = 6;

const int latchMin = 9;
const int latchHr = 10;

uint8_t prevMin = -1;
uint8_t currentMin = 0; //Shown time minute stored here
uint8_t currentHr = 0; //shown time hour stored here

long hourData = 0b00000000000010000000001000000000; //default to show 11
long minuteData = 0b10000000000010000000000000000000; //default to show 11

void setup()
{
  pinMode(7, OUTPUT);
  digitalWrite(7, HIGH); //pull HIGH minute blank pin so it never blank
  pinMode(8, OUTPUT);
  digitalWrite(8, HIGH); //pull HIGH hour blank pin so it never blank

  pinMode(12, OUTPUT);
  digitalWrite(12, HIGH); //pull HIGH hour invert pin so it never invert
  pinMode(13, OUTPUT);
  digitalWrite(13, HIGH); //pull HIGH minute invert pin so it never invert
  pinMode(4, OUTPUT);
  digitalWrite(4, LOW ); //pull LOW HV Shutdown so HV is always enabled

  pinMode(clkPin, OUTPUT);
  digitalWrite(clkPin, LOW);
  pinMode(dataHr, OUTPUT);
  digitalWrite(dataHr, LOW);
  pinMode(dataMin, OUTPUT);
  digitalWrite(dataMin, LOW);
  pinMode(latchMin, OUTPUT);
  digitalWrite(latchMin, LOW);
  pinMode(latchHr, OUTPUT);
  digitalWrite(latchHr, LOW);

  shiftOutData(dataMin, clkPin, latchMin, minuteData); //Send 0 to clear registers
  shiftOutData(dataHr, clkPin, latchHr, hourData); //Send 0 to clear registers

  delay(500); //wait 1/2 second for power to stabalize
  randomSeed(analogRead(A0)); //Read from floating A0 pin to seed Random number gen

  Serial.begin(115200);
  ss.begin(9600);
  Serial.println("Setup Complete");
}

void loop()
{
  while (ss.available()) {
    gps.encode(ss.read());
  }
  static unsigned long lastGPSTask = 0;
  const unsigned long gpsInterval = 500;
  if (millis() - lastGPSTask >= gpsInterval) {
    lastGPSTask = millis();
    
    if (gps.date.isValid() && gps.time.isValid() && gps.date.year() > 2000) {
      setTimeGPS(gps.date, gps.time); //sets values when GPS recieved

      if (gps.location.isValid()) {
        //debug print GPS coords
        //Serial.println(F("\n\nGPS Data Packet:"));
        //printFloat(gps.location.lat(), gps.location.isValid(), 11, 6);
        //printFloat(gps.location.lng(), gps.location.isValid(), 12, 6);

        float longitude = gps.location.lng(); //Save for math to calculate time zone
        //Eg. East coast is -75, so -75/15= -5 hours, West Coast is -120, so -120/15 = -8 hours
        TzoneOffset = round(longitude / 15.0); //rough calculation using every 15deg longitude = one hr time zone diff
      }
      stdOffsetMinutes = TzoneOffset * 60; //calculate minutes offset based on position
      dstOffsetMinutes = stdOffsetMinutes + 60; // add one 60 minutes for DaylightvSavings offset

      TimeChangeRule myDST = {"Daylight", Second, Sun, Mar, 2, dstOffsetMinutes}; // Daylight time = UTC - offset + 60 min
      TimeChangeRule mySTD = {"Standard", First, Sun, Nov, 2, stdOffsetMinutes};  // Standard time = UTC - offset
      Timezone myTZ(myDST, mySTD); //use daylight savings when matching dates above
      time_t localTime = myTZ.toLocal(now()); //set LocalTime to latest GPS data with Daylight savings & location applied

      currentMin = minute(localTime); //minutes are always minutes
      currentHr = getHour(localTime); //convert to 12hr time (from 24 hr)

      if (currentMin != prevMin) { //if the minute time has changed
        prevMin = currentMin;
        timeToBitMinute(currentMin); //convert time from integer to binary
        timeToBitHour(currentHr);
        shiftOutData(dataMin, clkPin, latchMin, minuteData); //send to tubes via shift register
        shiftOutData(dataHr, clkPin, latchHr, hourData);

        //Debugging:
        //Serial.print("\nTimeDisplayed");
        //Serial.print("\nhour ");
        //Serial.println(currentHr);
        //Serial.print("minute ");
        //Serial.println(currentMin);
        //Serial.print("sec ");
        //Serial.println(second());
        //End debugging
      }

    }
    else {
      //Serial.println(F("Waiting for GPS fix..."));
      DisplayRandomPattern(10); //show 10 random numbers on display
    }
  }


  //tube cleanging sequence runs twice a day, at 12:02
  if (currentHr == 12 && currentMin == 2 && TubeCleaning == true) {
    for (int i = 0; i <= 99; i += 11) { // Increment up by 11
      //Serial.print("Tube Cleaning: ");
      //Serial.println(i);
      timeToBitMinute(i);
      timeToBitHour(i);
      shiftOutData(dataMin, clkPin, latchMin, minuteData);
      shiftOutData(dataHr, clkPin, latchHr, hourData);
      delay(750);
    }
    for (int i = 88; i >= 0; i -= 11) { // Decrement down by 11
      //Serial.print("Tube Cleaning: ");
      //Serial.println(i);
      timeToBitMinute(i);
      timeToBitHour(i);
      shiftOutData(dataMin, clkPin, latchMin, minuteData);
      shiftOutData(dataHr, clkPin, latchHr, hourData);
      delay(750);
    }
    TubeCleaning = false; // End the tube cleaning after loop completes
    timeToBitMinute(2); //set the clock back to the correct time
    timeToBitHour(12);
    shiftOutData(dataMin, clkPin, latchMin, minuteData); //send to tubes via shift register
    shiftOutData(dataHr, clkPin, latchHr, hourData);
  }

  if (currentHr == 12 && currentMin == 10) {
    TubeCleaning = true; //setup for next crossover point
  }
}//end main loop

//===================Functions ===============================
//Send data to shift registers
void shiftOutData(uint8_t dataPin, uint8_t clockPin, uint8_t latchPin, uint32_t val)
{
  uint32_t mask = 1UL << 31;

  // Begin shifting data
  digitalWrite(latchPin, LOW);  // Keep latch low while loading data

  for (uint8_t i = 0; i < 32; i++) {
    // Write data bit (MSB first)
    digitalWrite(dataPin, (val & mask) ? HIGH : LOW);
    delayMicroseconds(1); //settle
    digitalWrite(clockPin, HIGH);    // Clock pulse
    delayMicroseconds(1); //settle
    digitalWrite(clockPin, LOW);
    delayMicroseconds(1); //settle
    mask >>= 1;
  }

  // Latch the data to outputs
  digitalWrite(latchPin, HIGH);
  delayMicroseconds(1); //settle
  digitalWrite(latchPin, LOW);
}
//PrintFloat Used for GPS Lat/Long Debugging
//static void printFloat(float val, bool valid, int len, int prec)
//{
//  if (!valid)
//  {
//    while (len-- > 1)
//      Serial.print('*');
//    Serial.print(' ');
//  }
//  else
//  {
//    Serial.print(val, prec);
//    int vi = abs((int)val);
//    int flen = prec + (val < 0.0 ? 2 : 1); // . and -
//    flen += vi >= 1000 ? 4 : vi >= 100 ? 3 : vi >= 10 ? 2 : 1;
//    for (int i = flen; i < len; ++i)
//      Serial.print(' ');
//  }
//}//end printfloat function


static void DisplayRandomPattern(int numCycles) {
  int randMin = 0;
  int randHr = 0;

  for (int i = 0; i < numCycles; i += 1) {
    randMin = random(0, 99);
    randHr = random(0, 99);
    timeToBitMinute(randMin); //show random number on minutes
    timeToBitHour(randHr); //show random number on hour
    shiftOutData(dataMin, clkPin, latchMin, minuteData);
    shiftOutData(dataHr, clkPin, latchHr, hourData);
    delay(100);
  }
}//end random pattern display function


static void setTimeGPS(TinyGPSDate & d, TinyGPSTime & t)
{
  //set the time (hr,min,sec,day,mnth,yr)
  setTime(t.hour(), t.minute(), t.second(), d.day(), d.month(), d.year());
}//end setimegps function

int getHour(time_t localTime)
{
  int hourIn = hour(localTime);
  if (hourIn > 12) {
    return (hourIn - 12);
  }
  else if (hourIn == 0) {
    return (12);
  }
  else {
    return (hourIn);
  }
}

void timeToBitMinute(uint8_t minutes)
{

  uint8_t Tens = (minutes / 10) % 10;
  uint8_t Ones = (minutes % 10);

  //Bit values are 0-31 in program, address pins on HV5622 1-32

  minuteData = 0b00000000000000000000000000000000;
  switch (Ones) {
    case 0:
      bitSet(minuteData, 10);
      break;
    case 1:
      bitSet(minuteData, 19);
      break;
    case 2:
      bitSet(minuteData, 18);
      break;
    case 3:
      bitSet(minuteData, 17);
      break;
    case 4:
      bitSet(minuteData, 16);
      break;
    case 5:
      bitSet(minuteData, 15);
      break;
    case 6:
      bitSet(minuteData, 14);
      break;
    case 7:
      bitSet(minuteData, 13);
      break;
    case 8:
      bitSet(minuteData, 12);
      break;
    case 9:
      bitSet(minuteData, 11);
      break;
    default:
      bitSet(minuteData, 11); //9
      // minuteData = 0b00000000000000000000000000000000;
      break;
  }
  switch (Tens) {
    case 0:
      bitSet(minuteData, 22);
      break;
    case 1:
      bitSet(minuteData, 31);
      break;
    case 2:
      bitSet(minuteData, 30);
      break;
    case 3:
      bitSet(minuteData, 29);
      break;
    case 4:
      bitSet(minuteData, 28);
      break;
    case 5:
      bitSet(minuteData, 27);
      break;
    case 6:
      bitSet(minuteData, 26);
      break;
    case 7:
      bitSet(minuteData, 25);
      break;
    case 8:
      bitSet(minuteData, 24);
      break;
    case 9:
      bitSet(minuteData, 23);
      break;
    default:
      bitSet(minuteData, 24); //8
      //minuteData = 0b00000000000000000000000000000000;
      break;
  }

}//end timeToBitMinute function

void timeToBitHour(uint8_t hours)
{
  uint8_t Tens = (hours / 10) % 10;
  uint8_t Ones = (hours % 10);

  //Bit values are 0-31 in program, address pins on HV5622 1-32

  hourData = 0b00000000000000000000000000000000;
  switch (Ones) {
    case 0:
      bitSet(hourData, 0);
      break;
    case 1:
      bitSet(hourData, 9);
      break;
    case 2:
      bitSet(hourData, 8);
      break;
    case 3:
      bitSet(hourData, 7);
      break;
    case 4:
      bitSet(hourData, 6);
      break;
    case 5:
      bitSet(hourData, 5);
      break;
    case 6:
      bitSet(hourData, 4);
      break;
    case 7:
      bitSet(hourData, 3);
      break;
    case 8:
      bitSet(hourData, 2);
      break;
    case 9:
      bitSet(hourData, 1);
      break;
    default:
      bitSet(hourData, 2); // 8
      //hourData = 0b00000000000000000000000000000000;
      break;
  }
  switch (Tens) {
    case 0:
      bitSet(hourData, 10);
      break;
    case 1:
      bitSet(hourData, 19);
      break;
    case 2:
      bitSet(hourData, 18);
      break;
    case 3:
      bitSet(hourData, 17);
      break;
    case 4:
      bitSet(hourData, 16);
      break;
    case 5:
      bitSet(hourData, 15);
      break;
    case 6:
      bitSet(hourData, 14);
      break;
    case 7:
      bitSet(hourData, 13);
      break;
    case 8:
      bitSet(hourData, 12);
      break;
    case 9:
      bitSet(hourData, 11);
      break;
    default:
      bitSet(hourData, 11); //9
      //  hourData = 0b00000000000000000000000000000000;
      break;
  }

}//end timeToBitHour function

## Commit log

2023-05-05 Commit all files
    Adding notes in readme and clean up some leftover project files
    [3D_ClockBase.ipt, 3D_ClockBase_hole.stl, BigCollar1.ipt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]
2023-05-05 File cleanup
    Update BOM
    [NixieClock_BOM.xlsx, NixieClock_backwardsTubes.kicad_pcb, Shift_boiis_in_front.kicad_pcb]
2025-05-05 Update SW libraries & code for 2025
    [NixieClock_BOM_2-21-25.xlsx]
